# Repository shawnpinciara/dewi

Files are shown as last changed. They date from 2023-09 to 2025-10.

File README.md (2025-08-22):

# The Diatonical Electric Wind Instrument project
By [Shawn Pinciara](https://www.instagram.com/shawnpinciara) and [Romeo Gabriele](https://linktr.ee/garaggio).

## Idea:
What if instead of having one hands position per note (on all the canonic wind instruments) you could enconde it more efficiently? _That's the reason why we built the DEWI_.

The notes of one scale can be encoded with 3 buttons (2^3 for the white keys) and 1 button more (to add all the sharps); now add another identical 4 buttons row (to keep your other hand entertained) and you can control with one hand the scale, and the other one the key/signature in wich the scale is played... a Diatonical EWI (aka DEWI).

Mapping the 4 buttons to the 12 notes has been a challenge but we found a good balance between beeing logical and organic:

## Project info:
Look at: https://shawnpinciara.github.io/dewi

## Make your own presets:
If you want to build your own DEWI and you don't have the same modules, you can make your own presets by chosing the BREATH type of sensor, the BUTTONS that you actually play, and what comes OUT from the instrument
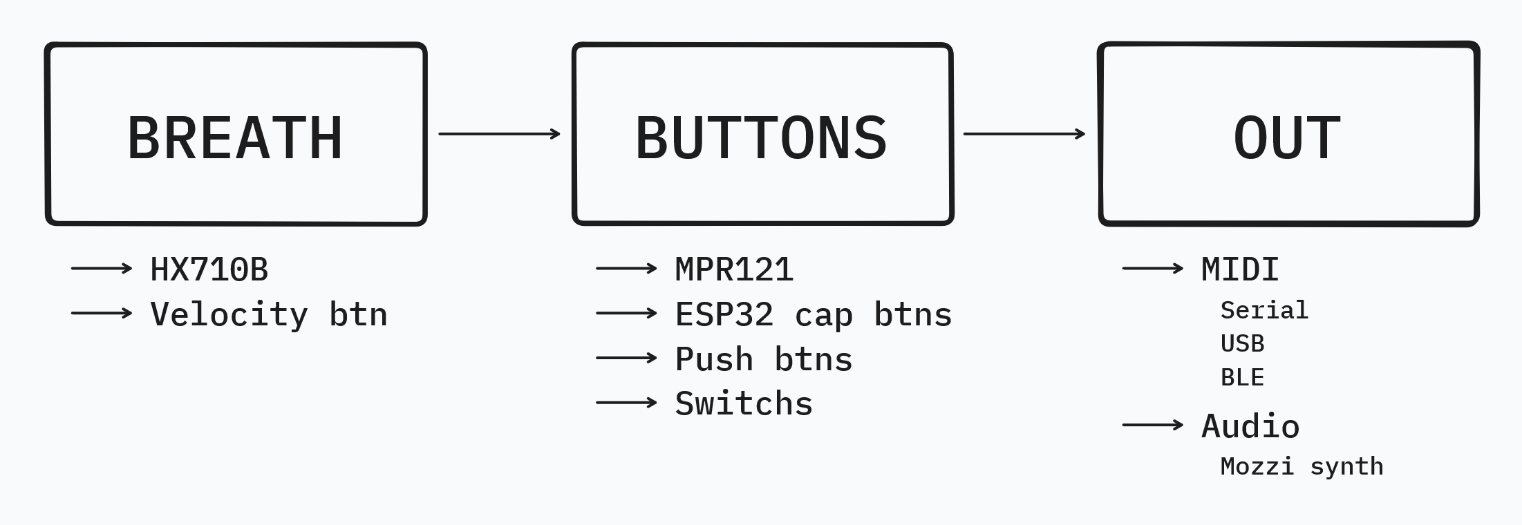
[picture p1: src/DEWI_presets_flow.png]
Preset flow

Every one of this pieces have a file, anche each file has some functions to be implemented in order to get the instrument to play (soon or later additional information will be added).
After implementing the funcions needed, you can make a preset file where you #include the 3 libraries, and reference that preset file in the DEWI.INO main file.
Presets can be found in the folder presets/ .

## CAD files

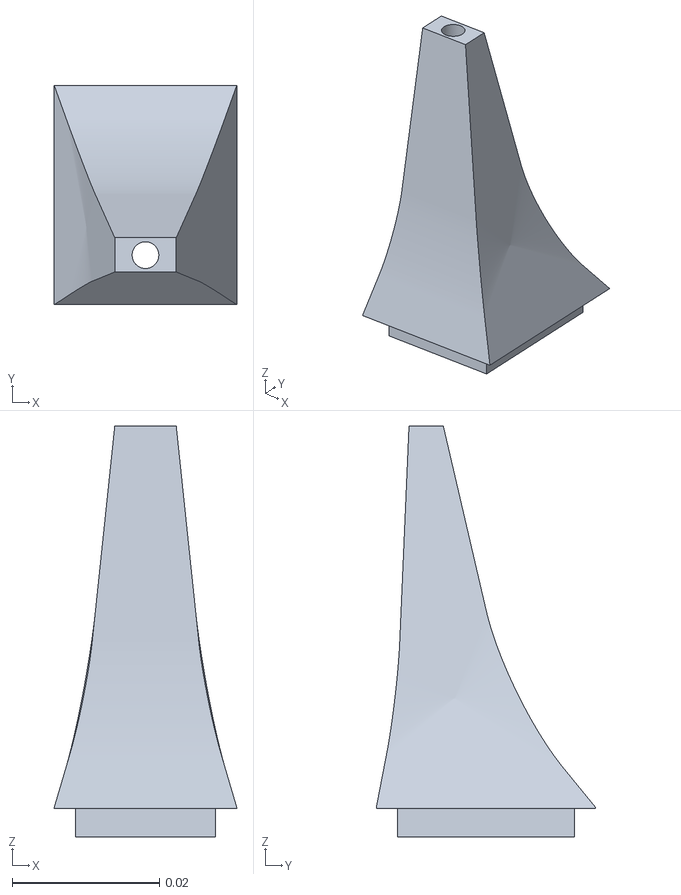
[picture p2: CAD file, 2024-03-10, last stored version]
src/blender/bocchino point.stl
0.0248 x 0.0298 x 0.0558

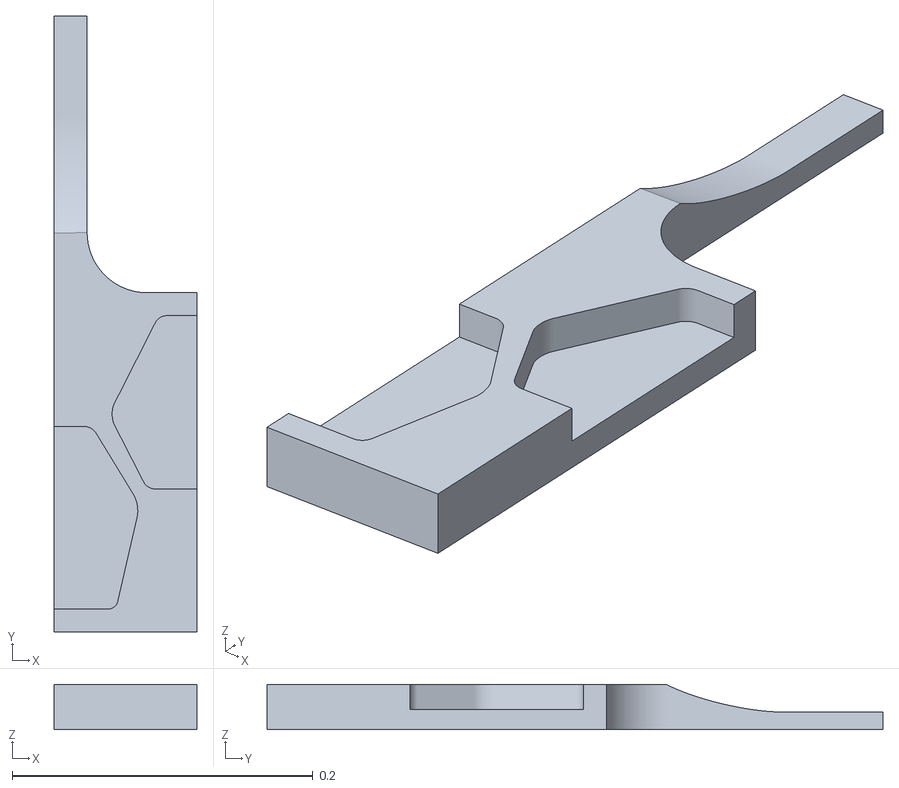
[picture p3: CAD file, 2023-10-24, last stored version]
src/keyboard dewi design/Design.stl
0.095 x 0.41 x 0.03

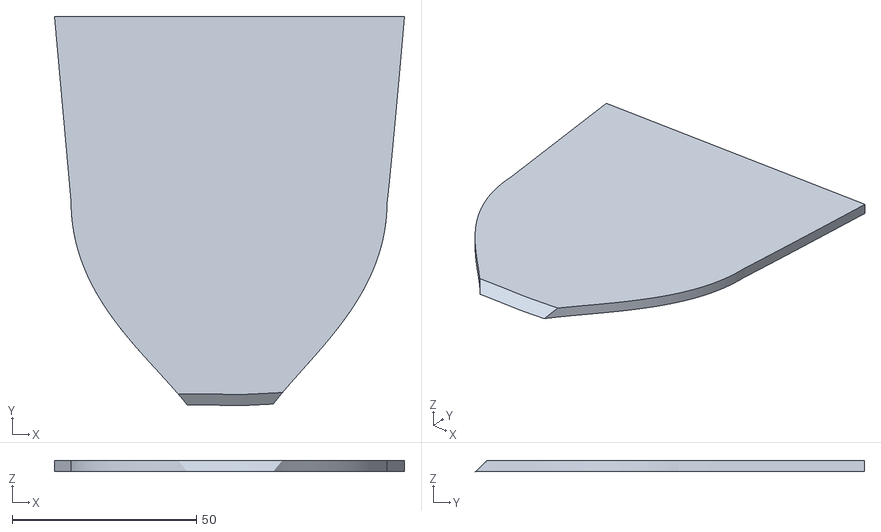
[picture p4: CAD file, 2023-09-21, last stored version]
src/Top.stl
94.9 x 105.5 x 3.00

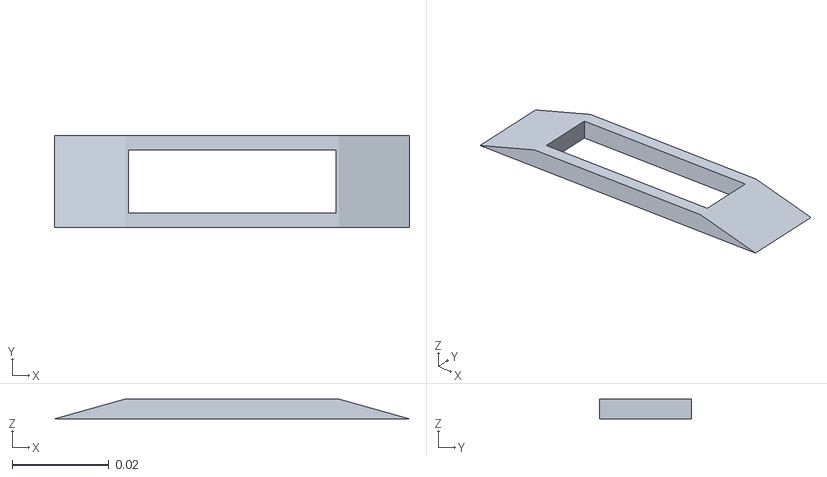
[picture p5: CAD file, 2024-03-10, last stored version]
src/blender/pitch wheel cover.stl
0.0736 x 0.019 x 0.00411

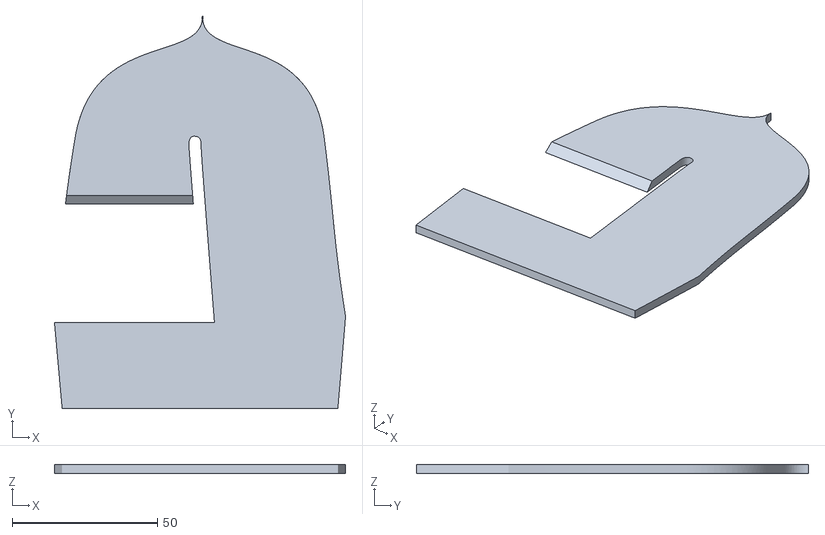
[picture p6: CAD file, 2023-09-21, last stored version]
src/Top 2.stl
100.2 x 135.0 x 3.00

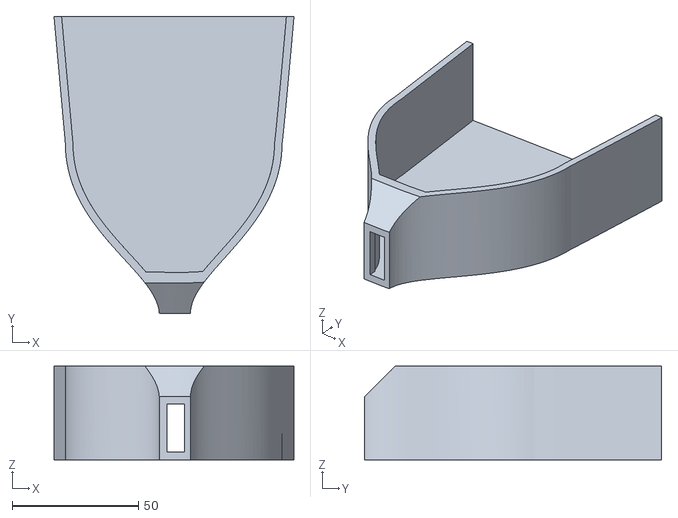
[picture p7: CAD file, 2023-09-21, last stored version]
src/Bottom.stl
94.9 x 117.5 x 37.0

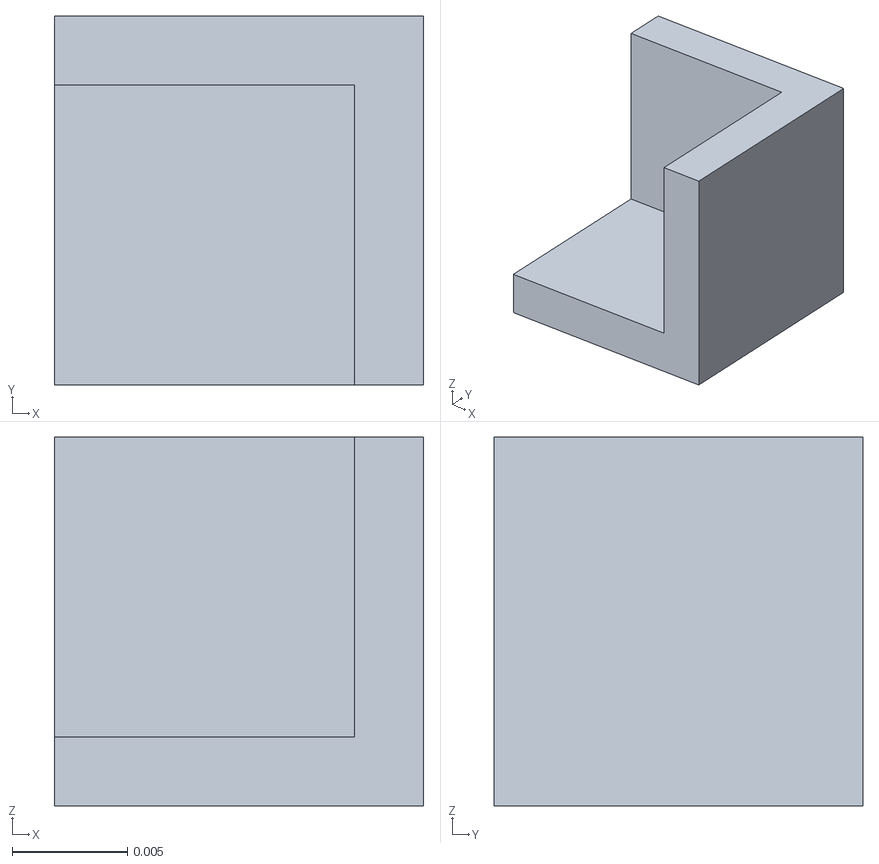
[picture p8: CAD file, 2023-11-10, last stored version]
src/blender/angolo.stl
0.016 x 0.016 x 0.016

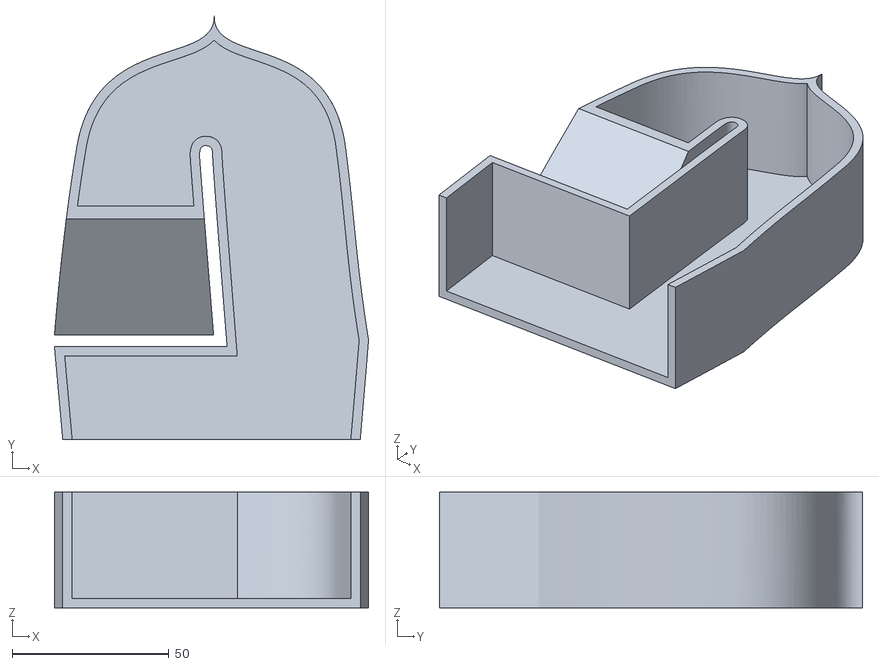
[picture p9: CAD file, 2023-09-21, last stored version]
src/Bottom 2.stl
100.2 x 135.0 x 37.0

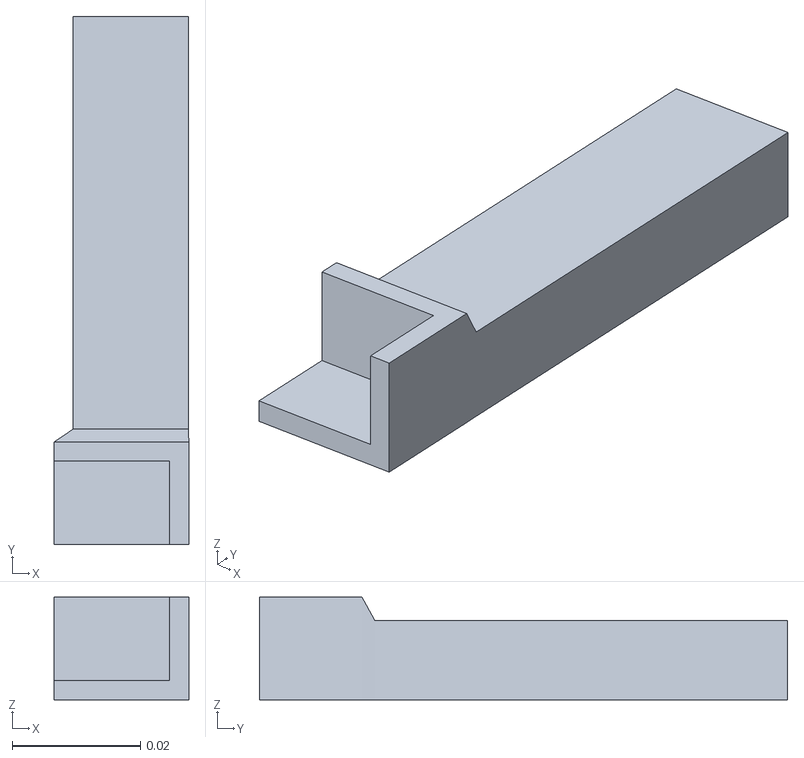
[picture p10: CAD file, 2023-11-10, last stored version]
src/blender/angolo1.stl
0.021 x 0.0824 x 0.016

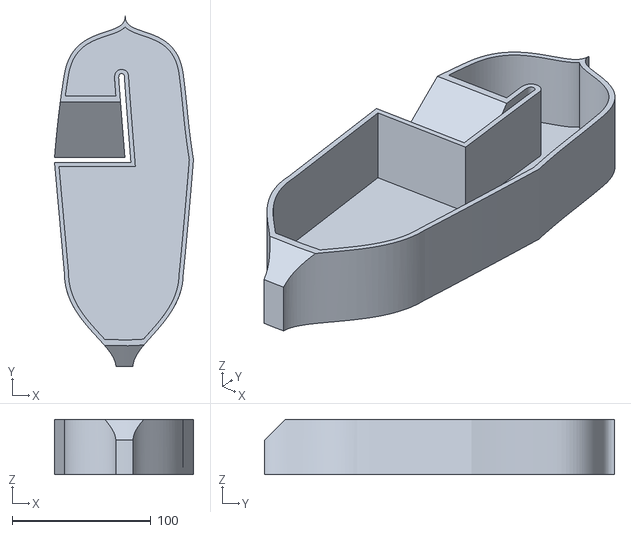
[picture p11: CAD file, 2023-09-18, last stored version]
src/Dewi corpo.stl
100.2 x 252.5 x 40.0

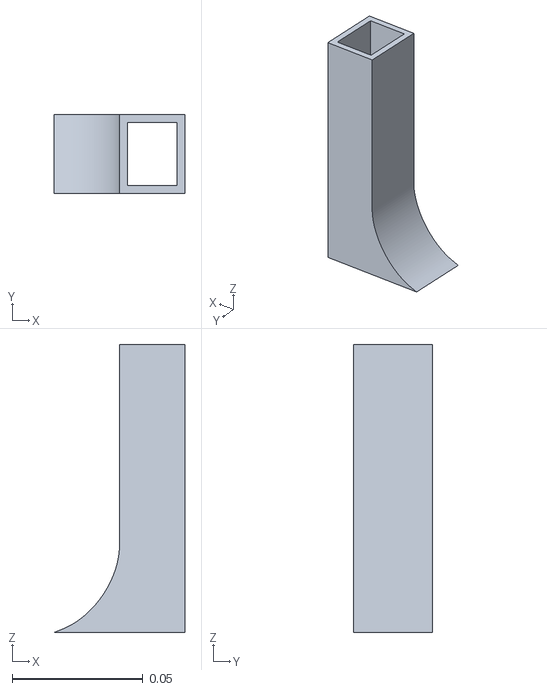
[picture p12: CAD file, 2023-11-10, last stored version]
src/blender/bocchino new.stl
0.05 x 0.03 x 0.11

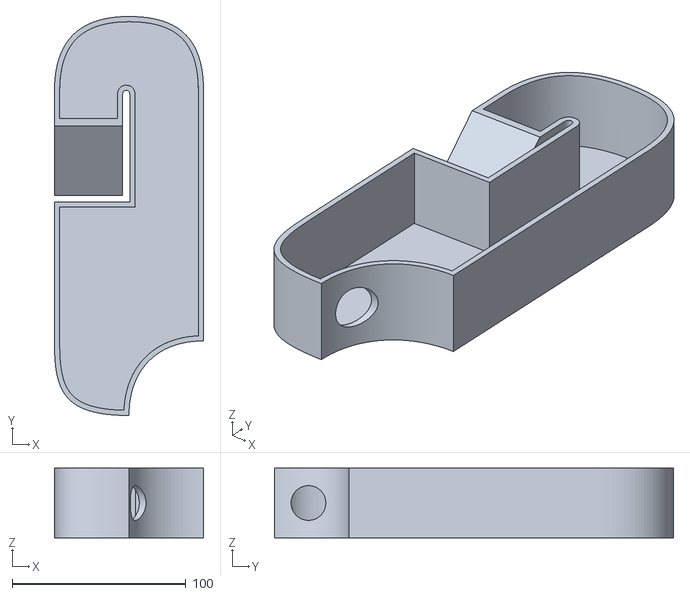
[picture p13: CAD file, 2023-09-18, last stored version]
src/Corpo1.stl
85.7 x 229.4 x 40.0

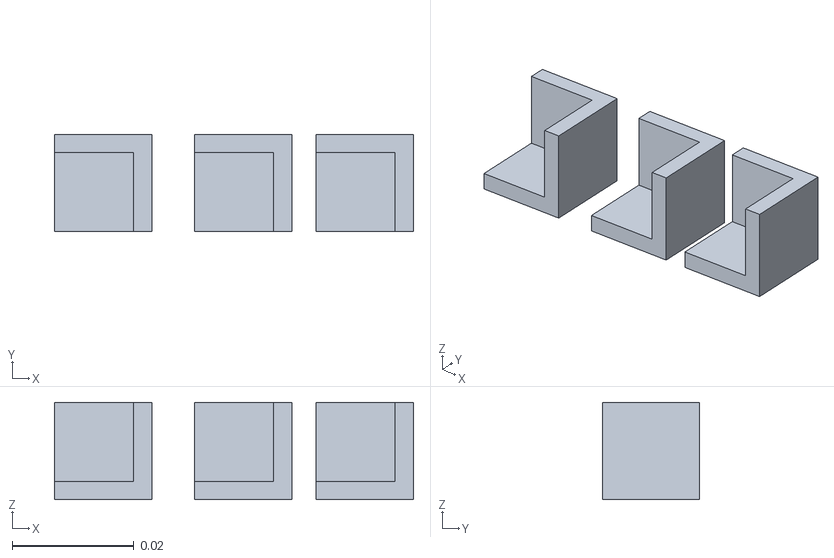
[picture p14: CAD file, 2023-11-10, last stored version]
src/blender/angolo2.stl
0.059 x 0.016 x 0.016

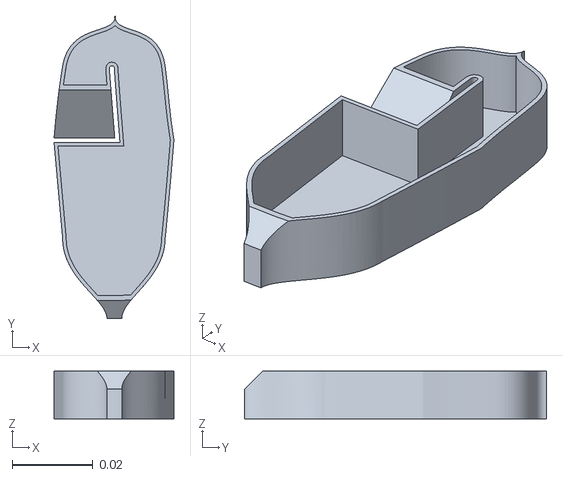
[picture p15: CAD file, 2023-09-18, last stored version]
src/To print.stl
0.0296 x 0.0746 x 0.0118

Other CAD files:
src/blender/bocchino.stl
src/forma.stl
src/blender/bocchino 3d print.stl
dEWI.blend
designs.blend
src/blend/bocchino.blend
src/blender/bocchino NEW.blend
src/blender/bocchino.blend
src/blender/dEWI.blend
src/blender/designs.blend
src/blender/dewi plegiglass angoli.blend
src/bocchino 3d print.stl
src/bocchino.stl
src/keyboard dewi design/Design.blend

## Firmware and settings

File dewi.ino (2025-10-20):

#include <Wire.h>
#include <Adafruit_Sensor.h>
#include <Adafruit_BNO055.h> //da installare
#include "Adafruit_MPR121.h" //da installare
#include <Adafruit_NeoPixel.h>
#include <utility/imumaths.h>
#include <MIDI.h>



/////////////////////// MAPPING
int vibrato_cc = 1; //41
int vibrato_min = 0;
int vibrato_max = 120;

int cutoff_cc = 74; //43
int cutoff_min = 50;
int cutoff_max =  127;

int modwheel_cc = 74; //43
int modwheel_min = 50;
int modwheel_max =  127;

//////////////////////

#define MIDI_SERIAL

#ifdef MIDI_SERIAL
  MIDI_CREATE_INSTANCE(HardwareSerial, Serial1, MIDI); //midi serial
#else
  MIDI_CREATE_DEFAULT_INSTANCE(); //midi usb
#endif
const int channel = 1;

// Which pin on the Arduino is connected to the NeoPixels?
#define PIN        6 // On Trinket or Gemma, suggest changing this to 1
#define NUMPIXELS 10 // Popular NeoPixel ring size
Adafruit_NeoPixel pixels(NUMPIXELS, PIN, NEO_GRB);

#ifndef _BV
#define _BV(bit) (1 << (bit)) 
#endif

//PINS
#define piezoPin1 8
#define modWheelPin 14
#define HX_OUT_PIN 3
#define HX_SCK_PIN 4


//binary no midi note map es: binary:0001 -> decimal: 1 -->note: D (1 in midi value)
const int noteArray[16] = {0,2,11,4,12,9,5,7,1,3,12,5,16,10,6,8};
const int keyArray[16] =  {0,2,11,4,0,9,5,7,1,3,0,5,1,10,6,8};
const int octaveArray[16] = {0,1,-1,0,-2,-1,-3,0,0,0,0,0,0,0,0,0}; //missing button is X000, change octave is 0X00, -1 (X) e +1 (Y) octave is 00XY
int octave = 5;


#define CONTROL_RATE 64 // Hz, powers of 2 are most reliable
unsigned int velocity = 60;
unsigned long threshold_bottom = 8700000; //base: 8067761
unsigned long hysteresis = 10500;
unsigned long threshold_top = 10000000;
unsigned long breath = 0; //16689194 base, 8595203 piano,10305762 forte (breath sensor data)
const uint16_t mask_key = 0b0000000011110000;
const uint16_t mask_note = 0b0000000000001111;
const uint16_t mask_octave = 0b0000011100000000;
//const uint16_t mask_cc = 0b0000100000000000;
uint16_t currentNote = 0;
uint16_t lastNote = 0b0111111111111111;
uint16_t sendNote;
uint16_t currentKey = 0;
uint16_t lastKey = 0;
uint16_t currentOctave = 0;
uint16_t lastOctave = 0;
uint16_t mpr121 = 0;
bool breathAttack = true;
bool breathRelease = false;
bool canSendNoteOnWhileBreathing = false;
int cc = 0;
int cc_debounce = 1;
int bank = 0;
int cutoff = 0;
int vibrato = 0;


//OUT
// #include "./serial_print.hpp"
#include "./midi_functions_serial.hpp"




//MODWHEEL
uint16_t modwheelVal = 999;
uint16_t modwheelValNew;

//TOUCH MODULE
//https://learn.adafruit.com/adafruit-mpr121-12-key-capacitive-touch-sensor-breakout-tutorial/overview

Adafruit_MPR121 mpr = Adafruit_MPR121();


/* Set the delay between fresh samples */
Adafruit_BNO055 bno = Adafruit_BNO055(55, 0x28, &Wire);



uint16_t getButtonsState() {
  return mpr.touched(); //valore letto da sensore (12 bit: 00000000000)
}



//BREATH SENSOR. HX710B
//https://swharden.com/blog/2022-11-14-hx710b-arduino/


enum HX_MODE { NONE, DIFF_10Hz, TEMP_40Hz, DIFF_40Hz};
const byte HX_MODE = DIFF_40Hz;

//BREATH READ FUNCTION
long getBreath() {
  // pulse clock line to start a reading
  for (char i = 0; i < HX_MODE; i++) {
    digitalWrite(HX_SCK_PIN, HIGH);
    digitalWrite(HX_SCK_PIN, LOW);
  }
  // wait for the reading to finish
  while (digitalRead(HX_OUT_PIN)) {}

  // read the 24-bit pressure as 3 bytes using SPI
  byte data[3];
  for (byte j = 3; j--;) {
    data[j] = shiftIn(HX_OUT_PIN, HX_SCK_PIN, MSBFIRST);
  }
  data[2] ^= 0x80;  // see note
  // shift the 3 bytes into a large integer
  long result = 0;
  result += (long)data[2] << 16;
  result += (long)data[1] << 8;
  result += (long)data[0];
  return result;
}

long getBreath2() {
  while (digitalRead(HX_OUT_PIN)) {}

  // read 24 bits
  long result = 0;
  for (int i = 0; i < 24; i++) {
    digitalWrite(HX_SCK_PIN, HIGH);
    digitalWrite(HX_SCK_PIN, LOW);
    result = result << 1;
    if (digitalRead(HX_OUT_PIN)) {
      result++;
    }
  }

  // get the 2s compliment
  result = result ^ 0x800000;

  // pulse the clock line 3 times to start the next pressure reading
  for (char i = 0; i < 3; i++) {
    digitalWrite(HX_SCK_PIN, HIGH);
    digitalWrite(HX_SCK_PIN, LOW);
  }

  return result;
}

void dump_regs() {
  Serial.println("========================================");
  Serial.println("CHAN 00 01 02 03 04 05 06 07 08 09 10 11");
  Serial.println("     -- -- -- -- -- -- -- -- -- -- -- --"); 
  // CDC
  Serial.print("CDC: ");
  for (int chan=0; chan<12; chan++) {
    uint8_t reg = mpr.readRegister8(0x5F+chan);
    if (reg < 10) Serial.print(" ");
    Serial.print(reg);
    Serial.print(" ");
  }
  Serial.println();
  // CDT
  Serial.print("CDT: ");
  for (int chan=0; chan<6; chan++) {
    uint8_t reg = mpr.readRegister8(0x6C+chan);
    uint8_t cdtx = reg & 0b111;
    uint8_t cdty = (reg >> 4) & 0b111;
    if (cdtx < 10) Serial.print(" ");
    Serial.print(cdtx);
    Serial.print(" ");
    if (cdty < 10) Serial.print(" ");
    Serial.print(cdty);
    Serial.print(" ");
  }
  Serial.println();
  Serial.println("========================================");
}
void allNotesOFF() {
  for (int i=0;i<127;i++) {
    MIDI.sendNoteOff(i,velocity,channel); 
  }
}

void setBreathThreshold() {
  int oldBreath = getBreath();
  for (int i=0;i<20;i++) {
    breath = getBreath();
    oldBreath = (oldBreath+breath)/2;
  }
  threshold_bottom = oldBreath;
}

const int FILTER_SIZE = 5; // Numero di campioni da mediare
int breath_samples[FILTER_SIZE];
int sample_index = 0;
// Variabile per la lettura filtrata
int filtered_breath = 0; 

int getFilteredBreath(int new_sample) {
    // Aggiorna il buffer
    breath_samples[sample_index] = new_sample;
    sample_index = (sample_index + 1) % FILTER_SIZE;
    
    // Calcola la media
    long sum = 0;
    for (int i = 0; i < FILTER_SIZE; i++) {
        sum += breath_samples[i];
    }
    filtered_breath = (int)(sum / FILTER_SIZE);
    return filtered_breath;
}

void printBinary(int number) {
  // Itera da 31 (il bit più significativo di un int a 32 bit) fino a 0.
  for (int i = 16; i >= 0; i--) {
    // Utilizza un'operazione bitwise AND per verificare se il bit i-esimo è impostato.
    // (1 << i) crea un '1' nella posizione del bit i.
    if ((number >> i) & 1) {
      Serial.print("1");
    } else {
      Serial.print("0");
    }
  }
  Serial.println(); // Aggiunge un ritorno a capo alla fine
}

int mapExponentialVolume(int breath_val, int breath_min, int breath_max) {
    // 1. Clampa il valore (assicura che sia nel range valido)
    int clamped_val = constrain(breath_val, breath_min, breath_max);

    // Calcola la dimensione totale dell'intervallo.
    int breath_range = breath_max - breath_min;
    
    // Evita la divisione per zero nel caso di breath_min == breath_max
    if (breath_range == 0) {
        return breath_min; 
    }

    // 2. Normalizza l'input: Mappa il fiato in un range da 0.0 a 1.0.
    // (Questo rappresenta la percentuale di fiato tra min e max).
    float normalized = (float)(clamped_val - breath_min) / (float)breath_range;

    // 3. Applica la Curva Esponenziale (Quadrato):
    // La curva trasforma il valore 0-1.0 in modo esponenziale.
    // Valori bassi (vicini a 0) diventano molto più piccoli (controllo fine).
    float curve_val = normalized * normalized; 
    
    // Se vuoi una curva ancora più aggressiva:
    // float curve_val = normalized * normalized * normalized;

    // 4. Scala il valore curvo [0.0, 1.0] nuovamente all'intervallo di output [breath_min, breath_max].
    // L'output deve partire da breath_min e estendersi per 'breath_range'.
    int output_value = (int)(curve_val * (float)breath_range) + breath_min;

    return output_value;
}

#include <math.h> // Necessario per expf()
int mapSigmoidVolume(int breath_val, int breath_min, int breath_max) {
    // 1. Pre-calcolo e Gestione del Caso Limite
    int breath_range = breath_max - breath_min;
    if (breath_range == 0) {
        return breath_min; 
    }

    // 2. Normalizzazione dell'Input: Mappa il fiato nell'intervallo [0.0, 1.0].
    float normalized = (float)constrain(breath_val, breath_min, breath_max);
    normalized = (normalized - breath_min) / (float)breath_range; 

    // 3. Traslazione e Scala per la Funzione Sigmoide Standard:
    // Mappa l'intervallo [0, 1] a [-6, 6] (dominio standard della curva a S).
    float x = (normalized * 12.0) - 6.0; 

    // 4. Applica la Curva Sigmoide (Logistica): f(x) = 1 / (1 + e^-x)
    // L'output 'sigmoid_output' è un valore curvo tra 0.0 e 1.0.
    float sigmoid_output = 1.0 / (1.0 + expf(-x));

    // 5. Riscalatura dell'Output: Mappa il valore curvo [0.0, 1.0] 
    // nuovamente all'intervallo di output [breath_min, breath_max].
    int output_value = (int)(sigmoid_output * (float)breath_range) + breath_min;

    return output_value;
}
void handleEvent(sensors_event_t* event) {
  
  // bno.getEvent(&angVelocityData, Adafruit_BNO055::VECTOR_GYROSCOPE);
  // bno.getEvent(&linearAccelData, Adafruit_BNO055::VECTOR_LINEARACCEL);
  // bno.getEvent(&magnetometerData, Adafruit_BNO055::VECTOR_MAGNETOMETER);
  // bno.getEvent(&accelerometerData, Adafruit_BNO055::VECTOR_ACCELEROMETER);
  // bno.getEvent(&gravityData, Adafruit_BNO055::VECTOR_GRAVITY);

  //handleEvent(&orientationData);
  // printEvent(&angVelocityData);
  // printEvent(&linearAccelData);
  // printEvent(&magnetometerData);
  // printEvent(&accelerometerData);
  // printEvent(&gravityData);
  double x = -1000000, y = -1000000 , z = -1000000; //dumb values, easy to spot problem
  if (event->type == SENSOR_TYPE_ACCELEROMETER) {
    Serial.print("Accl:");
    x = event->acceleration.x;
    y = event->acceleration.y;
    z = event->acceleration.z;
  }
  else if (event->type == SENSOR_TYPE_ORIENTATION) {
    //Serial.print("Orient:");
    x = event->orientation.x;
    y = event->orientation.y;
    z = constrain(event->acceleration.z,-60,0);
    //Serial.println(z);
    vibrato = map(z,-60,0,vibrato_min,vibrato_max);
    
  }
  else if (event->type == SENSOR_TYPE_MAGNETIC_FIELD) {
    Serial.print("Mag:");
    x = event->magnetic.x;
    y = event->magnetic.y;
    z = event->magnetic.z;
  }
  else if (event->type == SENSOR_TYPE_GYROSCOPE) {
    Serial.print("Gyro:");
    x = event->gyro.x;
    y = event->gyro.y;
    z = event->gyro.z;
  }
  else if (event->type == SENSOR_TYPE_ROTATION_VECTOR) {
    Serial.print("Rot:");
    x = event->gyro.x;
    y = event->gyro.y;
    z = event->gyro.z;
  }
  else if (event->type == SENSOR_TYPE_LINEAR_ACCELERATION) {
    Serial.print("Linear:");
    x = event->acceleration.x;
    y = event->acceleration.y;
    z = event->acceleration.z;
  }
  else if (event->type == SENSOR_TYPE_GRAVITY) {
    Serial.print("Gravity:");
    x = event->acceleration.x;
    y = event->acceleration.y;
    z = event->acceleration.z;
  }
  else {
    //Serial.print("Unk:");
  }

  // Serial.print("\tx= ");
  // Serial.print(x);
  // Serial.print(" |\ty= ");
  // Serial.print(y);
  // Serial.print(" |\tz= ");
  // Serial.println(z);
  // int8_t boardTemp = bno.getTemp();
  // Serial.println();
  // Serial.print(F("temperature: "));
  // Serial.println(boardTemp);
}


void setup() {
  Serial.begin(115200);

  MIDI.begin();

  pinMode(modWheelPin, INPUT);
  pinMode(HX_SCK_PIN, OUTPUT);
  pinMode(HX_OUT_PIN, INPUT);

  //MPR121 setup
  while (!Serial1) { // needed to keep leonardo/micro from starting too fast!
    delay(10);
  }
  Serial.println("cap.begin..");
  if (!mpr.begin(0x5A, &Wire,10,8,true)) {
    Serial.println("MPR121 not found, check wiring?");
    while (1);
  }
  Serial.println("MPR121 found!");
  delay(100);
  Serial.println("Initial CDC/CDT values:");
  //dump_regs(); //TODO: forse bisogna rimuovere questo

  //mpr.setAutoconfig(true);
  //mpr.setThreshholds(0x10, 0x0C); //10 -11 TODO: bisogna mettere valori che permettono letture stabili
  Serial.println("After autoconfig CDC/CDT values:");
  dump_regs();
  Serial.println("Orientation Sensor Test"); Serial.println("");
  if (!bno.begin()) {
    /* There was a problem detecting the BNO055 ... check your connections */
    Serial.print("Ooops, no BNO055 detected ... Check your wiring or I2C ADDR!");
    while (1);
  }
  monoMode(channel);
  delay(1000);
  Serial.println("Starting the DEWI");
  monoMode(channel);
  allNotesOFF();
  breath = 0;

  for (int i=0; i<10; i++) {
    breath = getBreath();
  }

  tone(piezoPin1,300);
  delay(300);
  noTone(piezoPin1);

  pixels.begin();
  pixels.setBrightness(60);
  pixels.fill(100);
  pixels.show();
  delay(400);
  pixels.fill(0);
  pixels.show();

  setBreathThreshold(); //set threshold

}


void updateDewi() {

  breath = getFilteredBreath(getBreath());
  mpr121 = getButtonsState();
  
  // Serial.print("Breath: ");
  // Serial.print(breath);
  // Serial.print(", delta: ");
  // Serial.println(abs(breath_samples[FILTER_SIZE-1]-breath_samples[0]));
  int delta = abs(breath_samples[FILTER_SIZE-1]-breath_samples[0]); //inclinazione della curva a 5 sample di distanza
  
  if (breath > threshold_bottom + hysteresis && breath < threshold_top) {
    mpr121 = getButtonsState();
    velocity = map(mapExponentialVolume(breath,threshold_bottom,threshold_top),threshold_bottom,threshold_top,40,127);
    currentKey = (mpr121 & mask_key)>>4;

    if (currentKey == 0) {
      currentKey = lastKey;
    }
    //color pixels as key pressed
    for (int i=0;i<4;i++) {
        int i_map = 1 << i;
        int brightness = ((currentKey & i_map) >> i) * 100; 
        pixels.setPixelColor(3-i, pixels.Color(0, 0, brightness));
        // Serial.print("keys: ");
        // Serial.print((currentKey & i_map) >> i);
    }
    //Serial.println();
    pixels.show();

    currentOctave = (mpr121 & mask_octave)>>8; 
    currentNote = ((octave+octaveArray[currentOctave])*12)+(noteArray[mpr121 & mask_note]+keyArray[currentKey]);
    // int t0 = millis();
    // while ((millis() - t0) < 20) {
    //     // busy waiting
    //     mpr121 = getButtonsState();
    // }
    

    if (breathAttack && delta>2000) { 
      breathAttack=false; breathRelease = true; canSendNoteOnWhileBreathing=true;
      int t0 = millis();
      while (millis()-t0 < 15) {
        mpr121 = getButtonsState();
        breath = getBreath();
      }
      velocity = constrain(map(breath,threshold_bottom,threshold_top,1,127),0,127);
      currentNote = ((octave+octaveArray[currentOctave])*12)+(noteArray[mpr121 & mask_note]+keyArray[currentKey]);
      if(velocity!=0) {
        MIDI.sendNoteOn(currentNote,velocity,channel);
        Serial.print("note on with vel: ");
        Serial.println(velocity);
      }
    } else { 
      if (currentNote != lastNote && canSendNoteOnWhileBreathing) {          
        //MIDI.sendNoteOff(lastNote,velocity,channel);  
        lastNote = currentNote;
        int t0 = millis();
        while (millis()-t0 < 15) {
          mpr121 = getButtonsState();
        }
        currentNote = ((octave+octaveArray[currentOctave])*12)+(noteArray[mpr121 & mask_note]+keyArray[currentKey]);
        MIDI.sendNoteOn(currentNote,velocity,channel);
        Serial.println("note on while breathing");
      }

    }
    if (breathRelease) {
      cutoff = constrain(map(breath,threshold_bottom,threshold_top,cutoff_min,cutoff_max),cutoff_min,cutoff_max);
      MIDI.sendControlChange(cutoff_cc,cutoff,channel);
      MIDI.sendControlChange(vibrato_cc,vibrato,channel);
      pixels.setPixelColor(4,pixels.Color(map(cutoff,cutoff_min,cutoff_max,0,255),0,0));
      pixels.setPixelColor(5,pixels.Color(map(vibrato,vibrato_min,vibrato_max,0,255),0,map(vibrato,vibrato_min,vibrato_max,0,100)));
      pixels.show();
      modwheelVal = constrain(analogRead(modWheelPin),350,650);
      modwheelVal = map(modwheelVal,650,350,MIDI_PITCHBEND_MIN,MIDI_PITCHBEND_MAX);
      
      //MIDI.sendPitchBend((int)modwheelVal,channel);
      Serial.print("modwheel ");
      Serial.print(modwheelVal);
      Serial.print(" ,cutoff ");
      Serial.print(cutoff);
      Serial.print(" ,vibrato ");
      Serial.print(vibrato);
      Serial.print(" ,breath ");
      Serial.print(breath);
      Serial.print(" , buttons: ");
      printBinary(mpr121);
    }

    

  } else { 
    if (breathRelease==true) { 
      breathAttack=true; breathRelease=false; canSendNoteOnWhileBreathing=false;
      MIDI.sendNoteOff(lastNote,velocity,channel);  
      Serial.println("note off");
      allNotesOFF();
      pixels.setPixelColor(4,pixels.Color(0,0,0));
      pixels.setPixelColor(5,pixels.Color(0,0,0));
      pixels.show();
      setBreathThreshold();
    }

  }

  lastKey = currentKey;
  
}


//MAIN
void loop() {
  updateDewi();
  //could add VECTOR_ACCELEROMETER, VECTOR_MAGNETOMETER,VECTOR_GRAVITY...
  sensors_event_t orientationData; //, angVelocityData , linearAccelData, magnetometerData, accelerometerData, gravityData
  bno.getEvent(&orientationData, Adafruit_BNO055::VECTOR_EULER);
  handleEvent(&orientationData);
  uint8_t system, gyro, accel, mag = 0;
  bno.getCalibration(&system, &gyro, &accel, &mag);
}

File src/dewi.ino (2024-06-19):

#include <Wire.h>

//OPTIONS:
#include "presets/preset_dewi_micro_mpr121.h"
//#include "presets/preset_shawn_minidewi.h"

const int piezoPin1 = 2;

//binary no midi note map es: binary:0001 -> decimal: 1 -->note: D (1 in midi value)
const int noteArray[16] = {0,2,11,4,12,9,5,7,1,3,12,5,16,10,6,8};
const int keyArray[16] =  {0,2,11,4,0,9,5,7,1,3,0,5,16,10,6,8};
const int octaveArray[16] = {0,1,-1,0,-2,-1,-3,0,0,0,0,0,0,0,0,0}; //missing button is X000, change octave is 0X00, -1 (X) e +1 (Y) octave is 00XY
int octave = 5;

#define CONTROL_RATE 64 // Hz, powers of 2 are most reliable
unsigned int velocity = 60;
unsigned long threshold_bottom = 9736143; //base: 8067761
unsigned long threshold_top = 14000000;
unsigned long breath = 0; //16689194 base, 8595203 piano,10305762 forte (breath sensor data)
const uint16_t mask_key = 0b0000000011110000;
const uint16_t mask_note = 0b0000000000001111;
const uint16_t mask_octave = 0b0000111100000000;
//const uint16_t mask_cc = 0b0000100000000000;
uint16_t currentNote = 0;
uint16_t lastNote = 0b0111111111111111;
uint16_t sendNote;
uint16_t currentKey = 0;
uint16_t lastKey = 1;
uint16_t currentOctave = 0;
uint16_t lastOctave = 0;
uint16_t mpr121 = 0;
bool breathAttack = true;
bool breathRelease = false;
int cc = 0;
int cc_debounce = 1;
int bank = 0;

void setup() {
  
  //Serial1.begin(31250);
  Serial.begin(115200);

  setupBreath();
  setupButtons();
  setupControls();
  setupMisc();

  tone(piezoPin1,300);
  delay(300);
  noTone(piezoPin1);
  monoMode(0);
  noteOn(0,60, 100);

}

// #ifdef mozzi:
// const int onTime=200; // in ms
// bool timeDebounce = true;
// unsigned long startTime =0;
// void updateControl(){
//   if(timeDebounce && millis()>startTime+onTime) {
//     timeDebounce = false;
//     startTime = millis();
//     //Serial.println(startTime);
//     updateBreath();
//   } 
  
//   if (millis()<startTime+onTime) {
//     timeDebounce = true;
//     //Serial.println(startTime);
//   }
// }
// #endif

void updateBreath() {
    breath = getBreath();
    if (breath > threshold_bottom) {
      mpr121 = getButtonsState();
      velocity = map(breath,threshold_bottom,threshold_top,40,127);
      lastKey = currentKey;
      currentKey = (mpr121 & mask_key)>>4;

      if (currentKey == 0) {currentKey = lastKey;}
      currentOctave = (mpr121 & mask_octave)>>8; 
      //cc = (mpr121 & mask_cc) >>11;
      currentNote = ((octave+octaveArray[currentOctave])*12)+(noteArray[mpr121 & mask_note]+keyArray[currentKey]);
      if (breathAttack) { 
        breathAttack=false; breathRelease = true;
        velocity = map(breath,threshold_bottom,threshold_top,40,127);
        noteOn(0,currentNote, velocity);
        Serial.println("note on");
      } else { 
        if (currentNote != lastNote) {          
          noteOff(0,lastNote,velocity);    
          lastNote = currentNote;
          noteOn(0,currentNote, velocity);  
        } else {
          PolyphonicKeyPressure(0, currentNote, velocity);
        }
      }
    } else { 
      if (breathRelease==true) { 
        breathAttack=true; breathRelease=false;
        noteOff(0,lastNote,velocity); 
      }  
    }
    lastNote = currentNote;
}


//MAIN
void loop() {
  
  // #ifndef mozzi:
  updateBreath();
  updateControls();
  // #endif

  // #ifdef mozzi:
  //   audioHook();
  // #endif
}

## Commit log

2023-04-18 Rebranch all stuff
    [designs.blend]
2023-05-16 ADDED example breath sensor new
2024-03-29 BLEMIDI inserted
2024-04-01 Updates ESP32 mode
2024-04-01 ESP32 with Mozzi basic working
2024-04-03 Revert "ESP32 with Mozzi basic working"
    This reverts commit 468092a58e52a21a0b83774ffd735223dbad228c.
    [breath_sensor.hpp, dewi.ino]
2024-06-14 Code uploads correctly
    [Design.blend, Design.stl, angolo.stl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]
